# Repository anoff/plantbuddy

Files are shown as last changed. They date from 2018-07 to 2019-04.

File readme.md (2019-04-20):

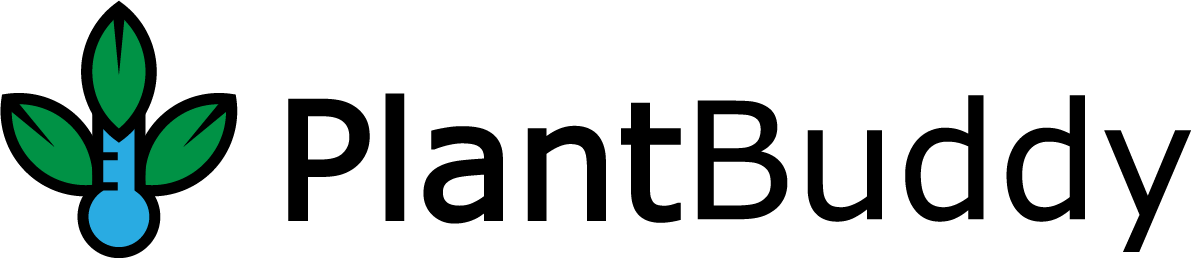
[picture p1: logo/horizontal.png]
plantbuddy





> nodeMCU based moisture monitoring for plants 🌱 with a serverless backend

## Main Features

1. Collect sensor readings every 15 minutes
1. Deep sleep to preserve battery
1. Submit values to serverless infrastructure using local WiFi network
1. Automatically fetch weather report for each reading using backend function
1. View sensor data on web page
1. Movable navigation panel
1. Mobile friendly page

### Webpage demo

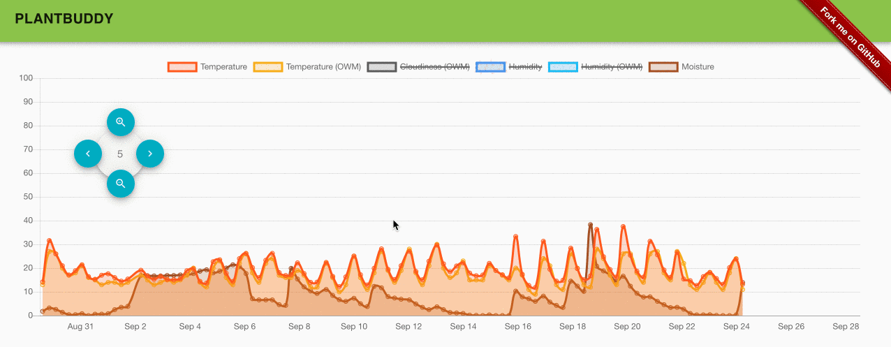
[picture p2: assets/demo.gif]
demo


### System Overview

system overview

## Hardware

The hardware setup consists of a [ESP8266](https://en.wikipedia.org/wiki/ESP8266) Microcontroller with a powersupply and two connected sensors.

- [DHT22](https://www.adafruit.com/product/385) connected to **D2** digital input pin
- [Soil moisture sensor](https://www.sparkfun.com/products/13322) connected to **A0**
- Bridge between **D0** and **RST** to enable deep sleep for optimizing battery life

> To program the ESP8266 you need to clear the connection to **RST**

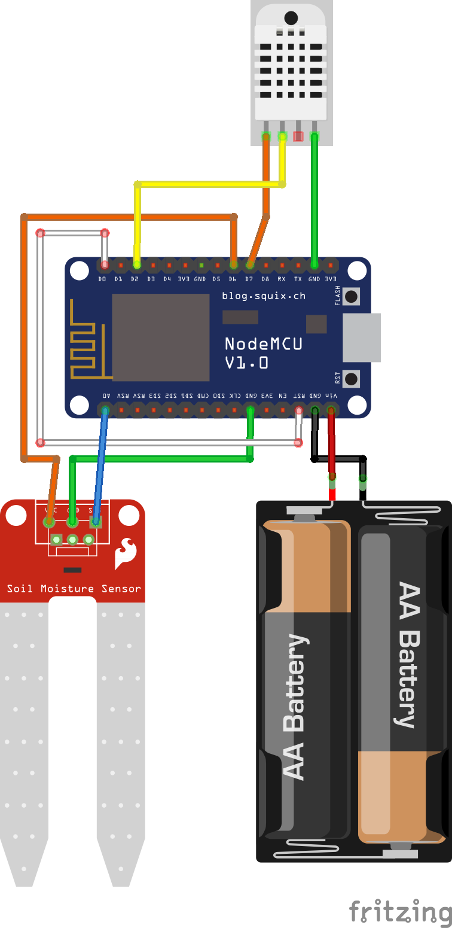
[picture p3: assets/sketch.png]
Fritzing diagram
[](assets/sketch.png)

### Power consumption

- ESP8266 draws `~80mA` when active and few `µA` when in deepsleep
- Maximum output current per GPIO pin is `12mA`
- Photo resistor has `10kOhm` resistor -> `3V3 / 10kOhm = 33mA`
- Moisture sensor consumes `35mA`
- DHT222 max current `2.5mA`

## Microcontroller

The ESP8266 chip is programmed with the [esp8266.ino file](esp8266.ino) using the [Arduino IDE](https://www.arduino.cc/en/Main/Software?). Secrets for connecting to local WiFi and endpoints to post data need to be defined in a `esp8266.secrets.c` file which is specified at [esp8266.secrets.template.c](esp8266.secrets.template.c).

esp8266 flowchart

## Setup

### Serverless backend

As a backend solution the plantbuddy runs on [Google's firebase 🔥](https://console.firebase.google.com) platform. The main functionalities used from firebase are:

1. Firestore database to store all sensor readings and heartbeats
1. Firebase functions for providing an **HTTP endpoint** as well as querying for **weather data** for each sensor reading

> Note: As outbound traffic is required to collect weather data, the project should run in **BLAZE** plan. Function and database usage should be within the free tier, only outbound traffic will be billed.

### Backend code

Before deploying the backend code several variables need to be set so the service can work correctly. An API token for [OpenWeatherMap](https://openweathermap.org/price) can be obtained from their website. A free account should suffice unless a _LOT_ of plantbuddies are running on one account.

```text
firebase functions:config:set owm.key=<OpenWeatherMap API Token>
firebase functions:config:set owm.city_id=2873776 // according to [OWM City ID List](https://openweathermap.org/current#cityid)
firebase functions:config:set header.secret=<some secret>
```

#### Local development

For developing the function locally:

```sh
# get a copy of the environment config
firebase functions:config:get > functions/.runtimeconfig.json
# start function host locally
firebase serve --only functions
```

## Deployment

All the Firebase stuff gets automatically deployed via Travis CI. To set it up create a encrypted token and update the [Travis CI Config](.travis.yml).

```sh
# create a firebase CI token
firebase login:ci

# encrypt the token to your project
docker run --rm caktux/travis-cli encrypt "<token from firebase login:ci>" -r anoff/plantbuddy
```

## Useful links

- https://openhomeautomation.net/esp8266-battery
- http://www.instructables.com/id/Interface-Moisture-Sensor-With-NodeMCU/
- https://www.losant.com/blog/getting-started-with-the-esp8266-and-dht22-sensor
- https://www.losant.com/blog/making-the-esp8266-low-powered-with-deep-sleep

## License

- The logo designed by [@reallinfo](https://github.com/reallinfo)
- The logo is licensed under a [Creative Commons Attribution 4.0 International License](https://creativecommons.org/licenses/by/4.0/)
- All sourcecode is licensed under [MIT](./LICENSE) unless stated otherwise

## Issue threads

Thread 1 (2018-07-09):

Power sensors via D OUT

anoff, 2018-07-09:
To prevent corrosion of the moisture sensor and power drain through the DHT unit they should be powered via digital output pins instead of permanent 3V3.

Closed 2018-07-14.

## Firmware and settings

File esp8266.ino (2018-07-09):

#include <ESP8266HTTPClient.h>
#include <ESP8266WiFi.h>
#include <DHT.h>
#include "esp8266.secrets.c"

#define PIN_MOISTURE_READ 0 // moisture sensor analog on PIN 0
#define PIN_MOISTURE_POWER 12 // D6
#define PIN_DHT_READ 4 // D2, temp + humidity sensor
#define PIN_DHT_POWER 13 // D7
#define DHT_TYPE DHT22
#define SLEEP_S 900 // how many seconds to sleep between readings
#define DEVICE_ID "plantbuddy1"
#define MAX_READING_RETRIES 10 // maximum number of retries when getting NaN values from sensor

DHT dht(PIN_DHT_READ, DHT_TYPE);

void setup() {
  pinMode(PIN_DHT_POWER, OUTPUT);
  pinMode(PIN_MOISTURE_POWER, OUTPUT);
  Serial.begin(115200);
  Serial.println("Starting setup");
  delay(100);
  digitalWrite(PIN_DHT_POWER, HIGH);
  digitalWrite(PIN_MOISTURE_POWER, HIGH);
  wifiConnect(WIFI_SSID, WIFI_KEY);
  // submit heartbeat
  Serial.println("Sending heartbeat..");
  int httpBeat = submitHeartbeat(POST_URL, DEVICE_ID);
  Serial.print("Heartbeat HTTP Response: ");
  Serial.println(httpBeat);
  delay(2000); // wait for DHT to power up?
  // read sensor values
  float moisture = getMoistureLevel(PIN_MOISTURE_READ);
  float humidity = dht.readHumidity();
  float temp = dht.readTemperature(false);
  float heatIndex = dht.computeHeatIndex(temp, humidity, false);
  int count = 0;
  while (isnan(humidity) || isnan(temp) || isnan(heatIndex)) {
    Serial.println("Error while reading sensor values, retrying");
    delay(2000);
    moisture = getMoistureLevel(PIN_MOISTURE_READ);
    humidity = dht.readHumidity();
    temp = dht.readTemperature(false);
    heatIndex = dht.computeHeatIndex(temp, humidity, false);
    count++;
    // force ESP into deepsleep so heartbeat gets out in case of permanent sensor damage
    if (count > MAX_READING_RETRIES) {
      shutdown();
    }
  }
  logSensorStatus(moisture, temp, humidity, heatIndex);
  Serial.println("Sending sensor data..");
  int httpCode = submitSensorStatus(POST_URL, moisture, temp, humidity, heatIndex);
  Serial.print("Sensor data HTTP response: ");
  Serial.println(httpCode);

  shutdown();
}

void loop() {
}

void shutdown() {
  digitalWrite(PIN_DHT_POWER, LOW);
  digitalWrite(PIN_MOISTURE_POWER, LOW);
  ESP.deepSleep(SLEEP_S * 1000000);
}
float getMoistureLevel(int PIN) {
  float moisture;
  moisture = analogRead(PIN);
  moisture = moisture/10;
  return moisture;
}

void logSensorStatus(float moisture, float temp, float humidity, float heatIndex) {
  Serial.print("Moisture Level: ");
  Serial.print(moisture);
  Serial.print("\t");
  Serial.print("Temperature: ");
  Serial.print(temp);
  Serial.print("\t");
  Serial.print("Humidity: ");
  Serial.print(humidity);
  Serial.print("\t");
  Serial.print("Heat Index: ");
  Serial.print(heatIndex);
  Serial.println("");
}

int submitSensorStatus(char* url, float moisture, float temp, float humidity, float heatIndex) {
  String json = "{";
  json += "\"moisture\": ";
  json += moisture;
  json += ", \"temp\": ";
  json += temp;
  json += ", \"humidity\": ";
  json += humidity;
  json += ", \"id\": \"";
  json += DEVICE_ID;
  json += "\"";
  json += ", \"type\": \"data\"";
  json += "}";
  int httpCode = httpPost(url, json);
  return httpCode;
}

int submitHeartbeat(char*  url, char* id) {
  String json = "{";
  json += "\"msg\": \"Still alive\"";
  json += ", \"id\": \"";
  json += id;
  json += "\"";
  json += ", \"type\": \"heartbeat\"";
  json += "}";
  int httpCode = httpPost(url, json);
  return httpCode;
}

// send HTTP post with JSON payload
int httpPost(char* url, String payload) {
  HTTPClient http;
  http.begin(url);
  http.addHeader("Content-Type", "application/json");
  if (HEADER_SECRET) {
    http.addHeader("SECRET", HEADER_SECRET);
  }
  int httpCode = http.POST(payload);
  String response = http.getString();
  if (httpCode < 0) {
    Serial.print("Error: ");
    Serial.println(http.errorToString(httpCode).c_str());
  }
  http.end();
  return httpCode;
}

// try to connect to given SSID and key, loop until successful
void wifiConnect(char* ssid, char* key) {
  WiFi.begin(ssid, key);
  Serial.print("Waiting for WiFi connection..");
  while (WiFi.status() != WL_CONNECTED) {
    Serial.print(".");
    delay(500);
  }
  Serial.println(".");
  Serial.print("Successfully connected to ");
  Serial.println(WiFi.SSID());
}

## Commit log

2018-07-04 :star2: feat: read dht22
    [sketch.fzz]
2018-07-06 :star2: feat: deep sleep and http post
    [sketch.fzz]
2018-07-07 :star2: feat: config url
    [sketch.fzz]
2018-07-07 :star2: feat: send heartbeat + device ID
2018-07-07 :page_facing_up: docs: power supply switch
    [sketch.fzz]
2018-07-07 :star2: feat: firebase function to create new sensor readings
2018-07-08 :star2: feat: POST sensor data to firebase function
2018-07-08 :page_facing_up: docs: overview and logic flowchart
2018-07-09 :star2: feat: power sensors via output pin
    [sketch.fzz]
2018-07-11 :page_facing_up: docs: add aggregates to diagram
    [sketch.fzz]
2018-07-11 :star2: feat: pan with buttons
2018-07-11 :ant: fix: hour aggregate function checking previous element instead of current
2018-08-04 :star2: feat: floaty action buttons
2018-08-04 :scissors: refactor: larger action button
2018-08-07 :ant: fix: hour aggregation to filter for correct elements
2019-05-07 fix(package): update material-design-icons-iconfont to version 5.0.1
2021-01-05 build(deps): bump dot-prop from 4.2.0 to 4.2.1 in /web
    Bumps [dot-prop](https://github.com/sindresorhus/dot-prop) from 4.2.0 to 4.2.1.
    - [Release notes](https://github.com/sindresorhus/dot-prop/releases)
    - [Commits](https://github.com/sindresorhus/dot-prop/compare/v4.2.0...v4.2.1)
